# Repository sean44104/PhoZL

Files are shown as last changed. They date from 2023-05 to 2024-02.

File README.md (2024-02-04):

# PhobGCCv2-HW
Seperate repository for the hardware used in the PhobGCC v2.0

The PhobGCC v2.0 board is licensed under CERN Open Hardware Licence Version 2 - Strongly Reciprocal.
This means that any changes made to the board should be made public and CHANGES.txt be updated to reflect said changes.

# CHANGES.txt
PhoZL is a version of the PhobGCCv2 PCB that adds a footprint for a left z button to the board, connecting to GND and GPIO12

In order to make these changes possible, the edge cuts and the tracks inside of the PCB have been modified; these changes are self evident.

PCB Ordering Guide: https://github.com/PhobGCC/PhobGCC-doc/blob/main/For_Makers/Phob2_JLCPCB_Ordering_Guide.md

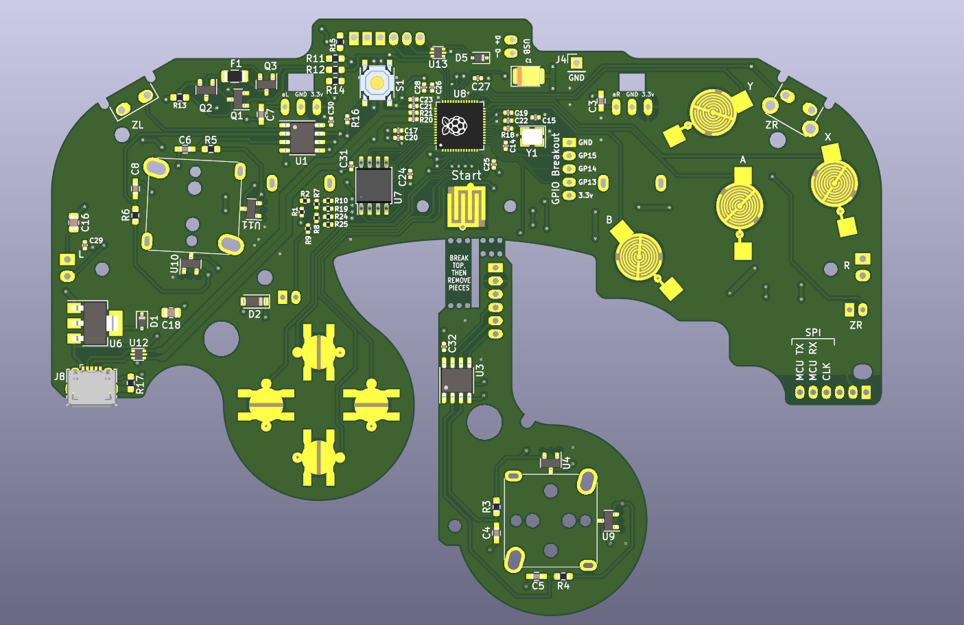
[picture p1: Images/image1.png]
PCB Front Render

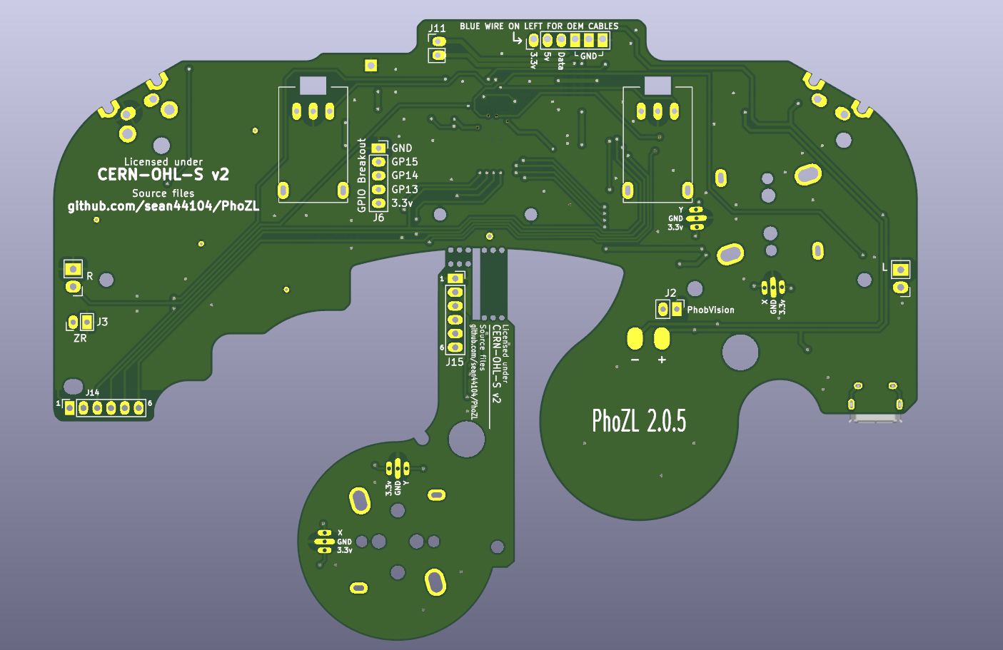
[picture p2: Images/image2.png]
PCB Back Render

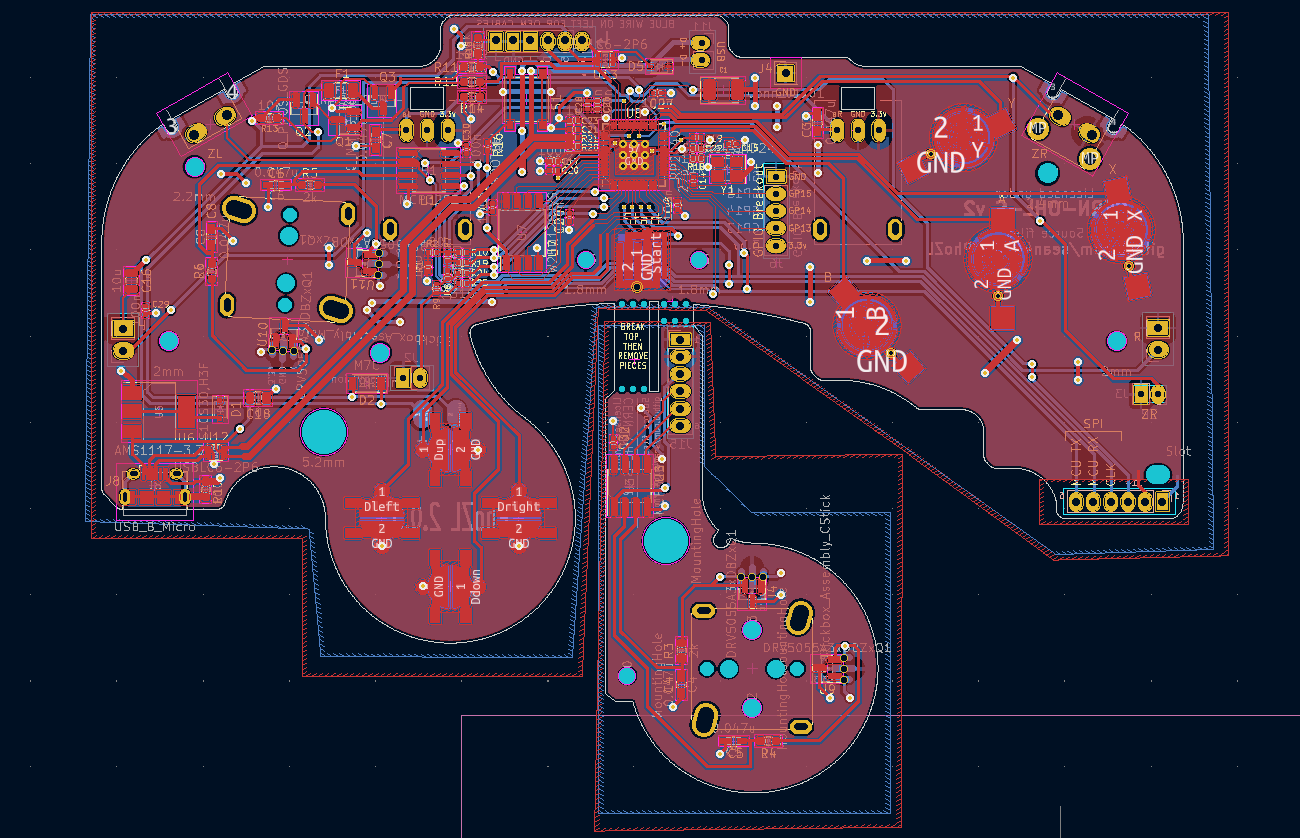
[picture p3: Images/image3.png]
PCB in KiCad


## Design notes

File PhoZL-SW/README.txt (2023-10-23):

These are modified PhobGCC v0.29 firmware uf2s. They add functionality to the PhoZL's Z button and allow it to be any digital input you want it to be. Please pick whichever one you like!

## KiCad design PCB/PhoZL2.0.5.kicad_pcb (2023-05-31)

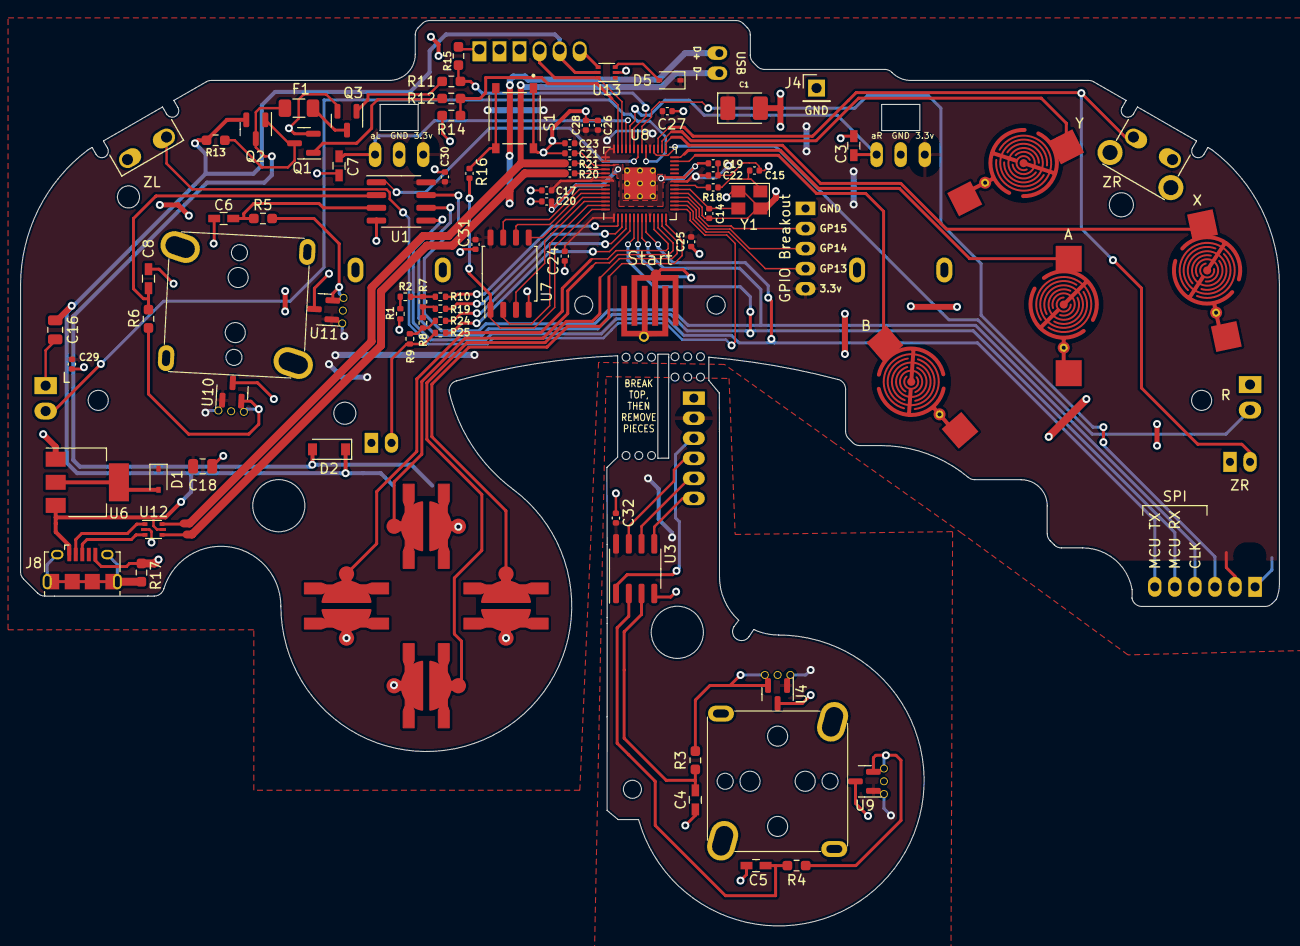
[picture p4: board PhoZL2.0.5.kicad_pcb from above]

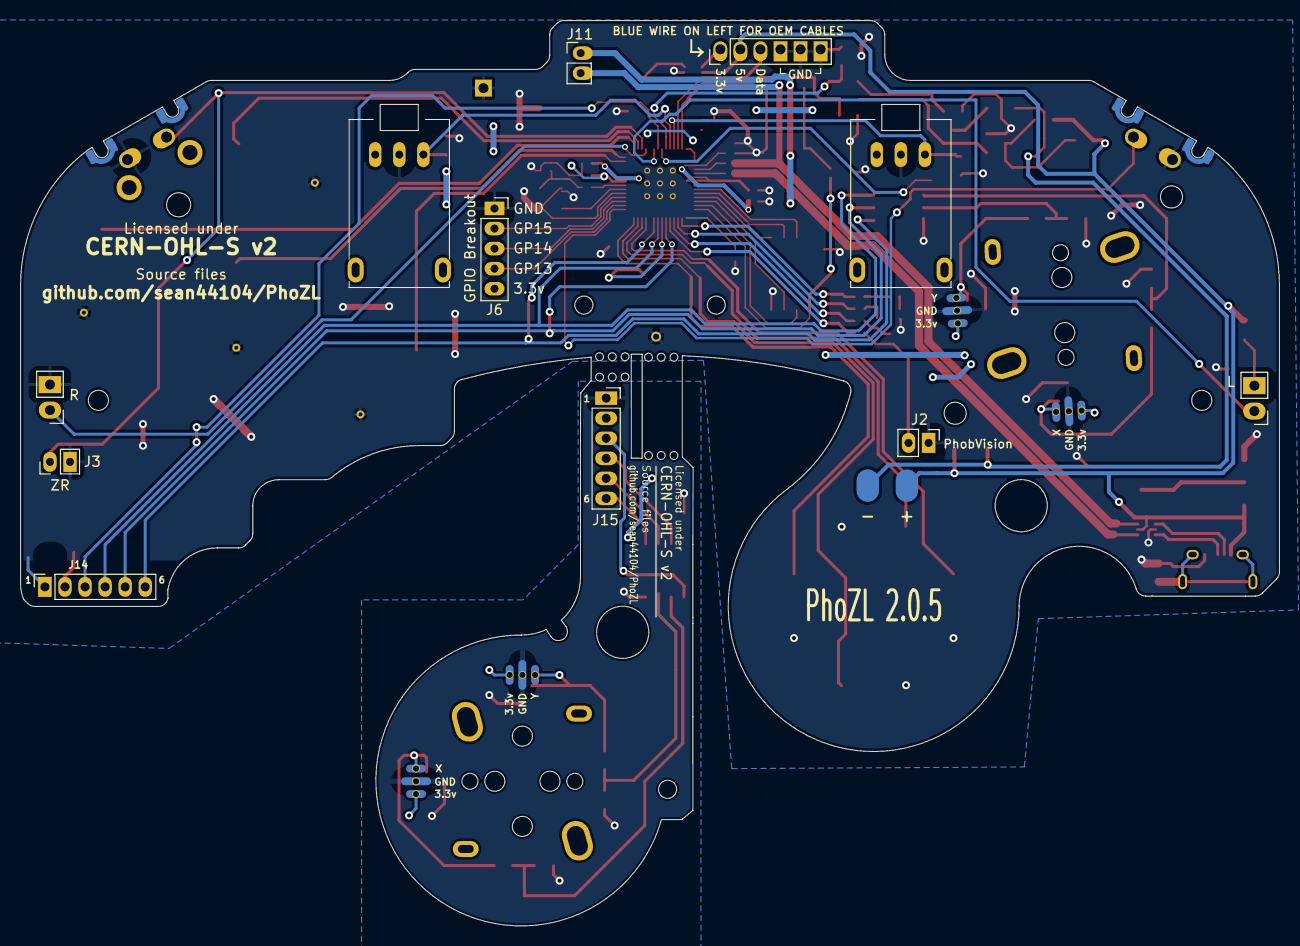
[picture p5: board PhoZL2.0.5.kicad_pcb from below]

Board: 2 copper layers, 125.5 x 90.3 mm, 111 parts (12 on the bottom side), 78 nets.

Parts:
C1: 47u; CP_EIA-3528-12_Kemet-T_Pad1.50x2.35mm_HandSolder
C3, C4, C5, C6, C7, C8: 0.047u; C_0603_HandSoldering
C14, C15: 27p; C_0402_1005Metric
C16, C18: 10u; C_0805_2012Metric
C17, C19, C20, C22, C24, C25, C26, C27, C28, C29, C30, C31, C32: 100n; C_0402_1005Metric
C21, C23: 1u; C_0402_1005Metric
D1, D5: CUS10S30,H3F; D_SOD-323
D2: M7C; D_SOD-123
F1: Fuse; Fuse_1206_3216Metric
H1: 5.2mm; MountingHole_5.2mm
H2: Slot
H3, H4: 2mm; MountingHole_2.0mm
H5, H6: 1.8mm; MountingHole_1.8mm
H7: 2.4mm; MountingHole_2.4mm
H8, H9: 2.2mm; MountingHole_2.2mm
H10: MountingHole; MountingHole_1.8mm
H11: MountingHole; MountingHole_5.2mm
H12, H13: MountingHole; MountingHole_2.0mm
H14: MouseBite; breakaway-mousebites-double-v2-small
H15: MouseBite; breakaway-mousebites-double-v2-large
J1: Conn_01x06_Female; GCC_Header_Straight_1x06_Pitch2.00mm
J2, J11: Conn_01x02; PinHeader_1x02_P2.00mm_Vertical
J3: Conn_01x02; PinHeader_1x02_P2.00mm_Horizontal
J4: Conn_01x01; PinHeader_1x01_P2.54mm_Vertical
J5: Rumble; rumble_pins
J6, J14, J15: Conn_01x06; PinSocket_1x06_P2.00mm_Vertical
J8: USB_B_Micro; USB_Micro-B_Amphenol_10118194_Horizontal
Q1, Q3: Q_NMOS_GSD; SOT-23
Q2: Q_PMOS_GDS; SOT-23
R1, R2, R7, R8, R9: 180; R_0402_1005Metric
R3, R4, R5, R6: 2k; R_0603_1608Metric_Pad0.98x0.95mm_HandSolder
R10, R19, R24, R25: 316; R_0402_1005Metric
R11, R12: 100R; R_0603_1608Metric_Pad0.98x0.95mm_HandSolder
R13, R14, R15: 10k; R_0603_1608Metric_Pad0.98x0.95mm_HandSolder
R16, R18: 1k; C_0402_1005Metric
R17: 100k; R_0603_1608Metric_Pad0.98x0.95mm_HandSolder
R20, R21: 27; C_0402_1005Metric
RV1, RV2: R_POT_MountingPin; GCC_Slider
S1: BOOTSEL; SW_TS-1187A-B-A-B
SW1: A; ABXY_Contact_Omron_Switch_Circley
SW2: B; ABXY_Contact_Omron_Switch_Circley
SW3: X; ABXY_Contact_Omron_Switch_Circley
SW4: Y; ABXY_Contact_Omron_Switch_Circley
SW5: Start; Start_Contact
SW6: L; Pin_Header_Straight_1x02_Pitch2.54mm
SW7: R; Pin_Header_Straight_1x02_Pitch2.54mm
SW8, SW8#2: Z; Z_Switch_Edge_Omron
SW9: Dleft; Dpad_Contact_TL3315NF_2
SW10: Dup; Dpad_Contact_TL3315NF_2
SW11: Dright; Dpad_Contact_TL3315NF_2
SW12: Ddown; Dpad_Contact_TL3315NF_2
U1, U3: MCP3202; SOIC-8_3.9x4.9mm_P1.27mm
U2: Stickbox_Assembly_Main; GCC_Stickbox_Hall_Only
U4, U9, U10, U11: DRV5055A3xDBZxQ1; SOT-23
U5: Stickbox_Assembly_CStick; GCC_Stickbox_Hall_Only
U6: AMS1117-3.3; SOT-223-3_TabPin2
U7: W25Q128JVS; SOIC-8_5.23x5.23mm_P1.27mm
U8: RP2040; RP2040-QFN-56
U12, U13: USBLC6-2P6; SOT-666
Y1: Crystal_GND24; Crystal_SMD_3225-4Pin_3.2x2.5mm

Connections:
+1V1: C19.1, C20.1, C21.1, U8.23 (DVDD), U8.45 (VREG_VOUT), U8.50 (DVDD)
+3V3: C1.1, C17.1, C18.1, C22.1, C23.1, C24.1, C25.1, C26.1, C27.1, C28.1, C29.1, C30.1, C31.1, D1.1 (K), D5.1 (K), J6.2, J14.2, RV1.1 (V+), RV2.1 (V+), U1.8 (VDD/VREF), U2.1 (H1XV), U2.4 (H1YV), U7.8 (VCC), U8.1 (IOVDD), U8.10 (IOVDD), U8.22 (IOVDD), U8.33 (IOVDD), U8.42 (IOVDD), U8.43 (ADC_AVDD), U8.44 (VREG_IN), U8.48 (USB_VDD), U8.49 (IOVDD), U10.1 (VCC), U11.1 (VCC)
+5V: C16.1, D2.1 (K), J1.2, J5.1, J8.1 (VBUS), Q2.2 (S), R13.2, U6.3 (VI), U12.5 (VBUS), U13.5 (VBUS)
/A: SW1.1, U8.28 (GPIO17)
/B: SW2.1, U8.27 (GPIO16)
/Brake: R12.1, R14.2, U8.41 (GPIO29_ADC3)
/CLK: J14.4, U1.7 (CLK), U8.8 (GPIO6)
/CLK2: J15.4, U3.7 (CLK)
/CS1: U1.1 (~CS/SHDN), U8.36 (GPIO24)
/CS2: J14.3, U8.35 (GPIO23)
/CS2_2: J15.3, U3.1 (~CS/SHDN)
/C_x_filt: C5.1, R4.1, U3.2 (CH0)
/C_y_filt: C4.1, R3.1, U3.3 (CH1)
/Ddown: SW12.1, U8.13 (GPIO10)
/Din: J14.6, U1.5 (DIN), U8.9 (GPIO7)
/Din2: J15.6, U3.5 (DIN)
/Dleft: SW9.1, U8.11 (GPIO8)
/Dout: J14.5, U1.6 (DOUT), U8.6 (GPIO4)
/Dout2: J15.5, U3.6 (DOUT)
/Dright: SW11.1, U8.14 (GPIO11)
/Dup: SW10.1, U8.12 (GPIO9)
/GCC_3.3V: J1.1, U13.4 (I/O2)
/GCC_DATA: J1.3, U8.40 (GPIO28_ADC2), U13.6 (I/O1)
/GND_C: C4.2, C5.2, C32.2, J15.1, U3.4 (VSS), U4.3 (GND), U5.2 (H1XG), U5.5 (H1YG), U9.3 (GND)
/GPIO12: SW8#2.2, U8.15 (GPIO12)
/GPIO13: J6.3, U8.16 (GPIO13)
/GPIO14: J6.4, U8.17 (GPIO14)
/GPIO15: J6.5, U8.18 (GPIO15)
/H1XS: R6.2, U2.3 (H1XS), U10.2 (OUT)
/H1YS: R5.2, U2.6 (H1YS), U11.2 (OUT)
/H2XS: R4.2, U5.3 (H1XS), U9.2 (OUT)
/H2YS: R3.2, U4.2 (OUT), U5.6 (H1YS)
/L: SW6.1, U8.34 (GPIO22)
/Ladder1: R10.2, U8.2 (GPIO0)
/Ladder2: R19.2, U8.3 (GPIO1)
/Ladder3: R24.2, U8.4 (GPIO2)
/Ladder4: R25.2, U8.5 (GPIO3)
/Lanalog: C7.1, RV1.3 (Signal), U8.39 (GPIO27_ADC1)
/QSPI_SCLK: U7.6 (CLK), U8.52 (QSPI_SCLK)
/QSPI_SD0: U7.5 (DI(IO0)), U8.53 (QSPI_SD0)
/QSPI_SD1: U7.2 (DO(IO1)), U8.55 (QSPI_SD1)
/QSPI_SD2: U7.3 (IO2), U8.54 (QSPI_SD2)
/QSPI_SD3: U7.7 (IO3), U8.51 (QSPI_SD3)
/QSPI_SS: R16.1, U7.1 (~CS), U8.56 (QSPI_SS)
/R: SW7.1, U8.32 (GPIO21)
/Ranalog: C3.1, RV2.3 (Signal), U8.38 (GPIO26_ADC0)
/Rumble: R11.1, R15.2, U8.37 (GPIO25)
/Start: SW5.1, U8.7 (GPIO5)
/Stick_x_filt: C8.1, R6.1, U1.2 (CH0)
/Stick_y_filt: C6.1, R5.1, U1.3 (CH1)
/USB_D+: J11.1, R20.1, U12.4 (I/O2)
/USB_D+_Raw: J8.3 (D+), U12.3 (I/O2)
/USB_D-: J11.2, R21.1, U12.6 (I/O1)
/USB_D-_Raw: J8.2 (D-), U12.1 (I/O1)
/V: J2.2, R9.1, R25.1
/X: SW3.1, U8.29 (GPIO18)
/XIN: C14.1, U8.20 (XIN), Y1.3
/XOUT: R18.1, U8.21 (XOUT)
/Y: SW4.1, U8.30 (GPIO19)
/Z: J3.2, SW8.1, U8.31 (GPIO20)
/~USB_BOOT: R16.2, S1.C, S1.D
GND: C1.2, C3.2, C6.2, C7.2, C8.2, C14.2, C15.2, C16.2, C17.2, C18.2, C19.2, C20.2, C21.2, C22.2, C23.2, C24.2, C25.2, C26.2, C27.2, C28.2, C29.2, C30.2, C31.2, J1.4, J1.5, J1.6, J2.1, J3.1, J4.1, J6.6, J8.5 (GND), J14.1, Q1.2 (S), Q3.2 (S), R1.2, R14.1, R15.1, R17.2, RV1.2 (GND), RV2.2 (GND), S1.A, S1.B, SW1.2, SW2.2, SW3.2, SW4.2, SW5.2, SW6.2, SW7.2, SW8.2, SW8#2.1, SW9.2, SW10.2, SW11.2, SW12.2, U1.4 (VSS), U2.2 (H1XG), U2.5 (H1YG), U6.1 (GND), U7.4 (GND), U8.19 (TESTEN), U8.57 (GND), U10.3 (GND), U11.3 (GND), U12.2 (GND), U13.2 (GND), Y1.2, Y1.4
unnamed: C15.1, R18.2, Y1.1
unnamed: D1.2 (A), U6.2 (VO)
unnamed: D2.2 (A), F1.1, J5.2, Q2.3 (D)
unnamed: D5.2 (A), U13.3 (I/O2)
unnamed: F1.2, Q3.3 (D)
unnamed: J8.6 (Shield), R17.1
unnamed: Q1.1 (G), R12.2
unnamed: Q1.3 (D), Q2.1 (G), R13.1
unnamed: Q3.1 (G), R11.2
unnamed: R1.1, R2.2
unnamed: R2.1, R7.2, R10.1
unnamed: R7.1, R8.2, R19.1
unnamed: R20.2, U8.47 (USB_DP)
unnamed: R21.2, U8.46 (USB_DM)
unnamed: R8.1, R9.2, R24.1
VCC: C32.1, J15.2, U3.8 (VDD/VREF), U4.1 (VCC), U5.1 (H1XV), U5.4 (H1YV), U9.1 (VCC)

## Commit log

2022-12-13 altered the files on my fork to reflect the changes described in changes.txt
    [PhoZL-2.0.2.kicad_pcb, PhobGCC_2_0_0_proto_1.kicad_sch]
2022-12-13 added images and updated the silkscreen
    [PhoZL-2.0.2.kicad_pcb]
2022-12-13 image display and gerbers
    [PhoZL-2.0.2-B_Cu.gbl, PhoZL-2.0.2-B_Mask.gbs, PhoZL-2.0.2-B_Silkscreen.gbo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]
2022-12-16 12-16-22 Changes
    pcb has been redone on the newest version of the 2.0.2 pcb
    (my dpad was added to the main pcb!)
    gpio15 on zl changed to gpio12
    removed the zl input from the GPIO breakout, instead going directly into the rp2040
    [PhoZL-2.0.2.kicad_pcb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]
2022-12-20 12-20-22 Changes
    slight updates to the silkscreen
    USB Data + / - as well as the GND at the top of the PCB has been relocated
    (Credit to Plants for the idea!)
    [PhoZL-2.0.2.kicad_pcb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]
2022-12-23 12-23-22 Changes
    updated dpad to match current phob 2
    [PhoZL-2.0.2.kicad_pcb]
2023-05-31 2.0.5 Update
    [10118194C.igs, 10118194c.stp, FH34SRJ-12S-0.5SH.igs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]

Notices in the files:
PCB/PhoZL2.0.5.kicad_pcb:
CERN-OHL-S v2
